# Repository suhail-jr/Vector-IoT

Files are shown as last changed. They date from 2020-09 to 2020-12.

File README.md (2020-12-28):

# Vector-IoT
Vector IoT : World’s smallest and powerful fully opensource  fully-featured ESP32 development board designed to unlock the power of the ESP32’s dual-core 240MHz and internet connectivity, in a package smaller than your thumb! Order your pcb from [jlcpcb.com](https://jlcpcb.com)

 ~ Current Status: Prototype boards sponsored by [jlcpcb.com](https://jlcpcb.com) ~
     
     Note: This design was performed in Eagle 9.2.0 , you will need a atleast eagle 9.2.0 or higher version to open and edit these source files. 
           # Chance for bugs : High

# Rendered Footage of the PCB

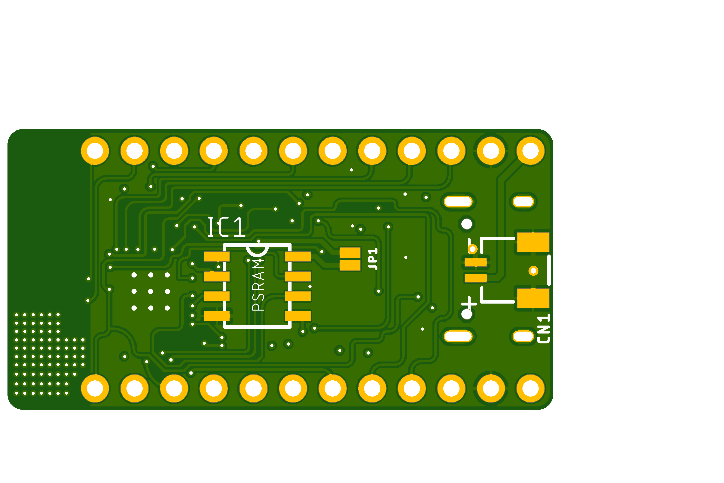
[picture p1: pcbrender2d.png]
Render

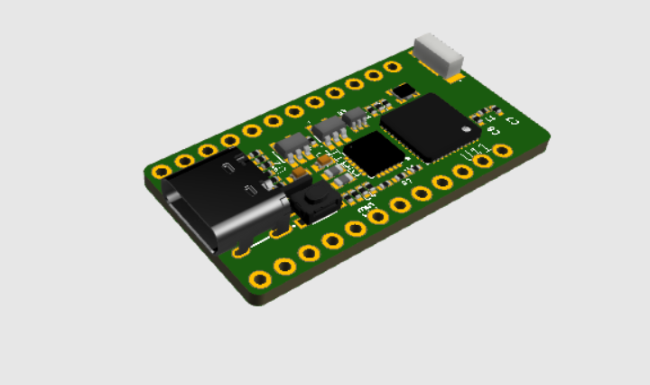
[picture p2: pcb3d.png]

## Licence
 * Hardware in this repository is licenced under Creative Commons BY-SA

 ## OSHW Certification
 TBD (Will apply when prototypes tested)

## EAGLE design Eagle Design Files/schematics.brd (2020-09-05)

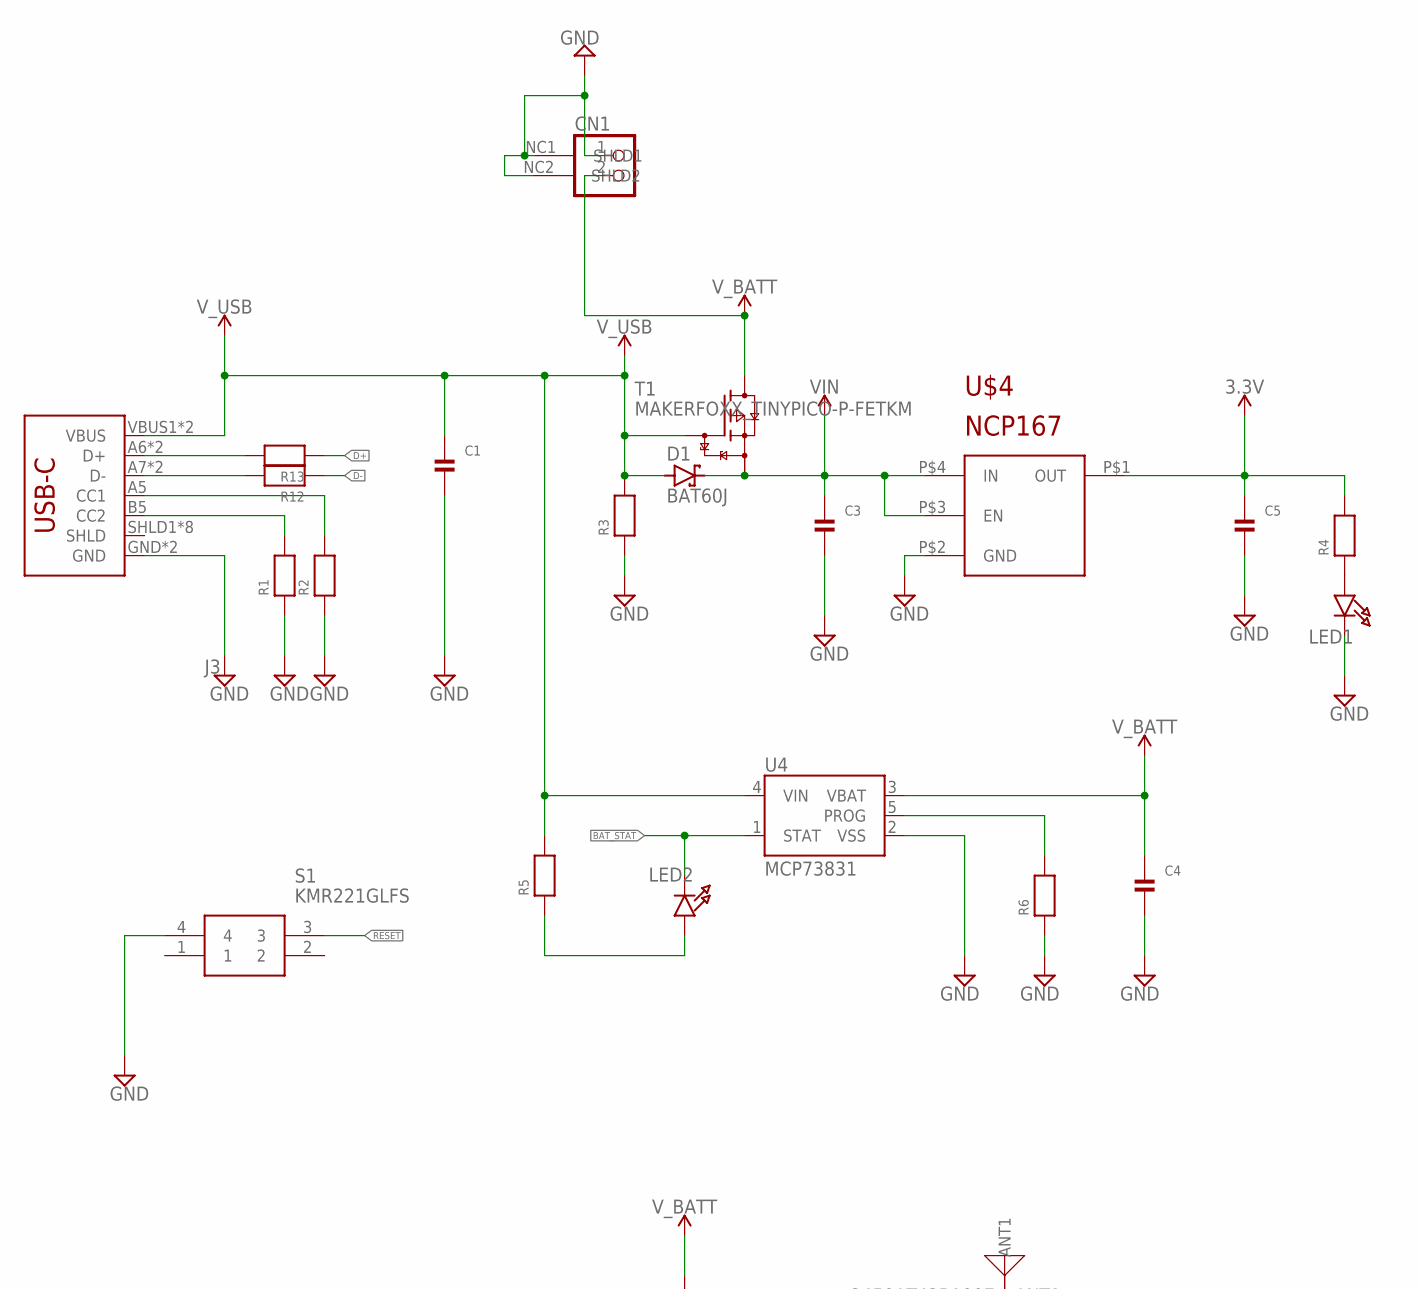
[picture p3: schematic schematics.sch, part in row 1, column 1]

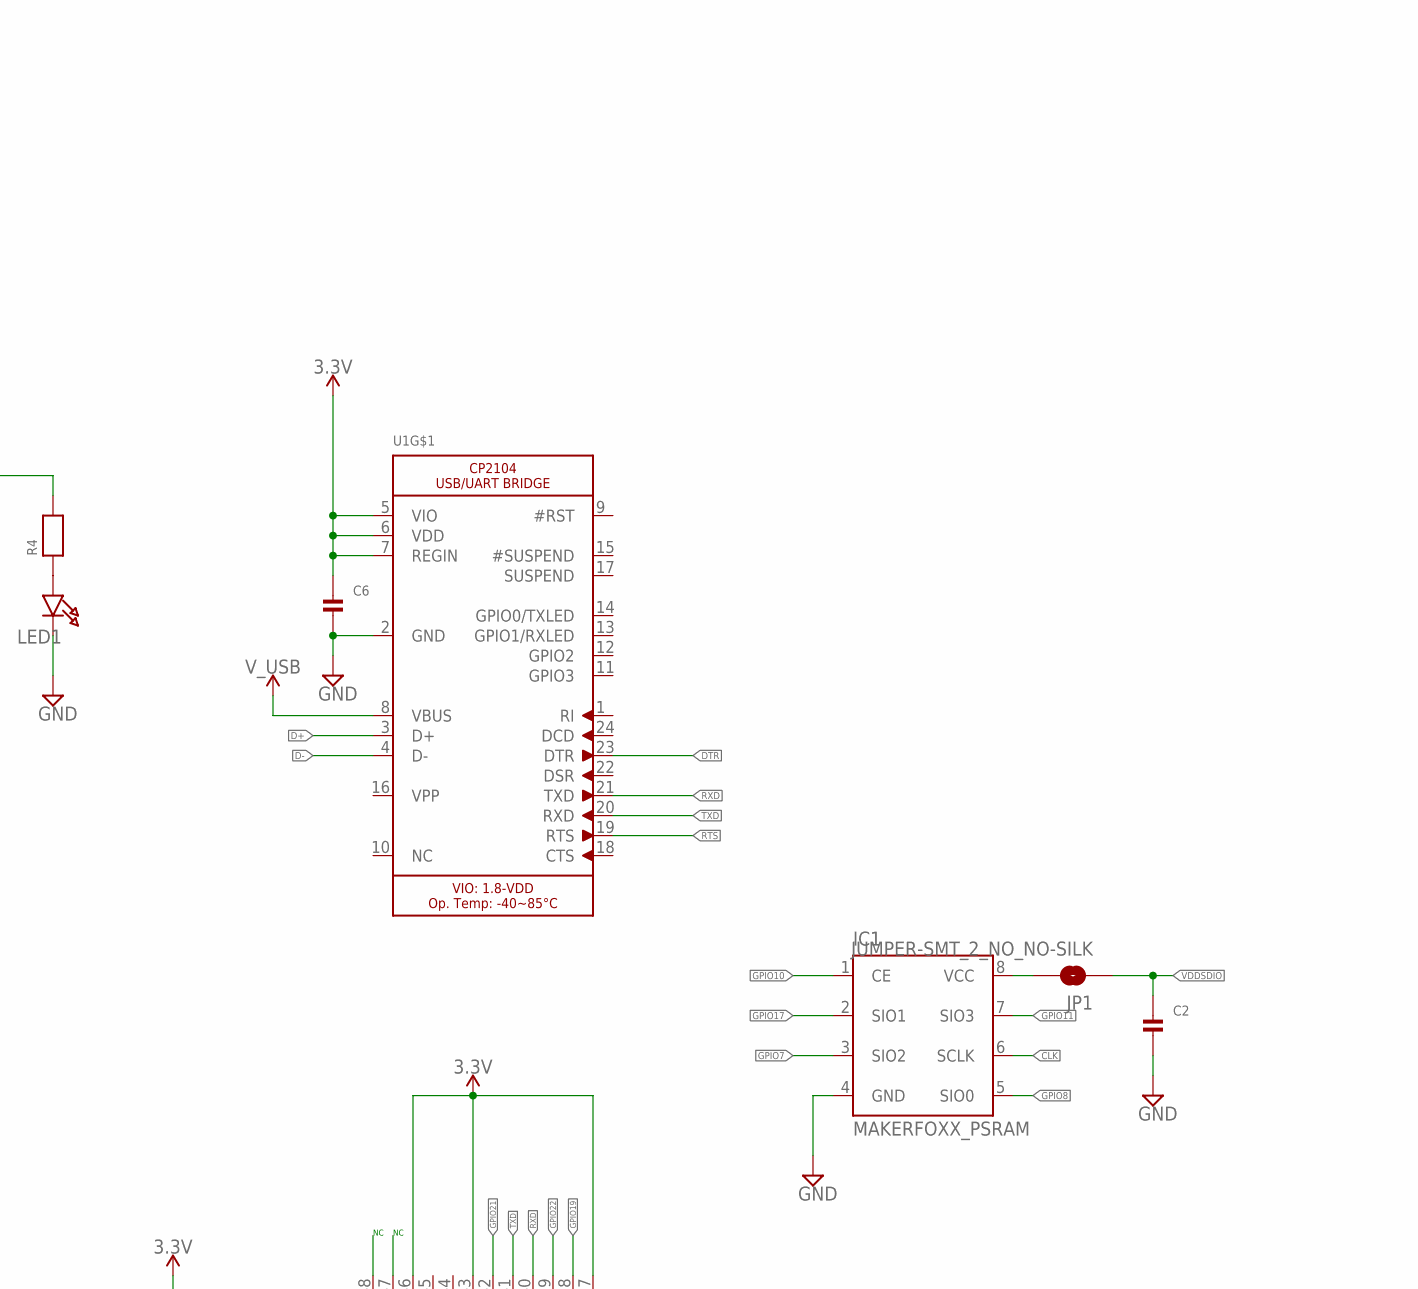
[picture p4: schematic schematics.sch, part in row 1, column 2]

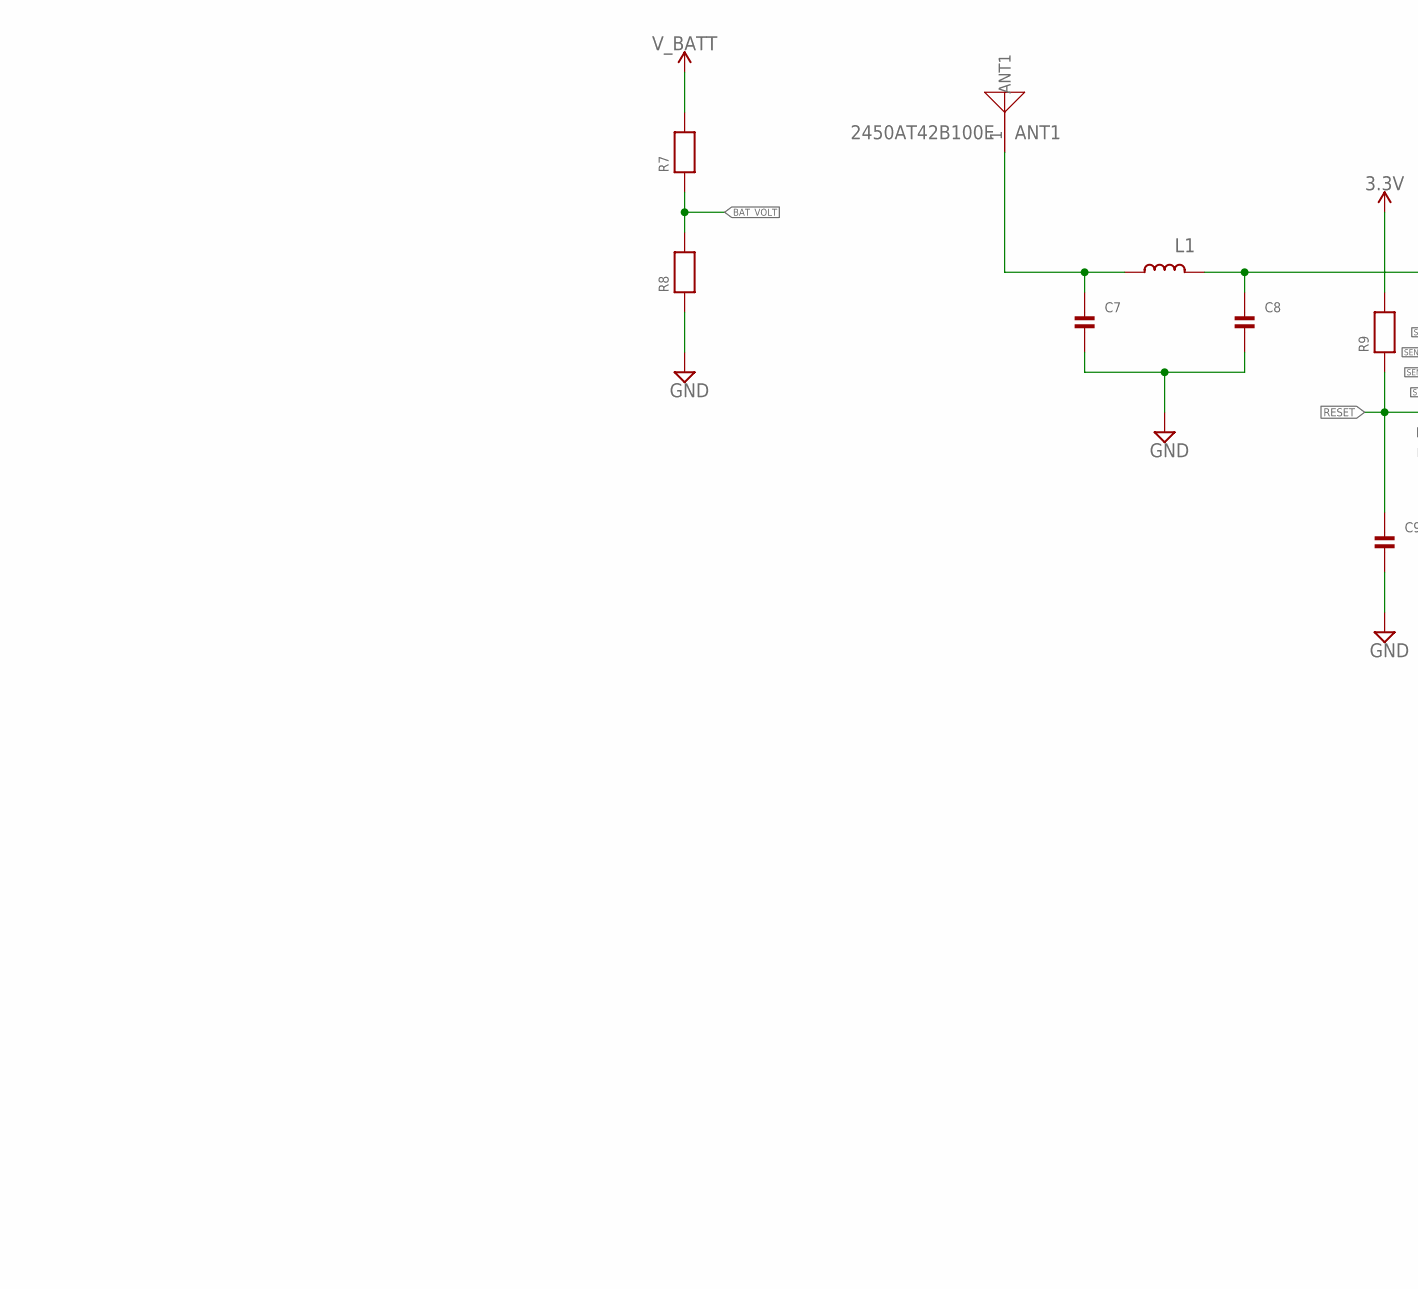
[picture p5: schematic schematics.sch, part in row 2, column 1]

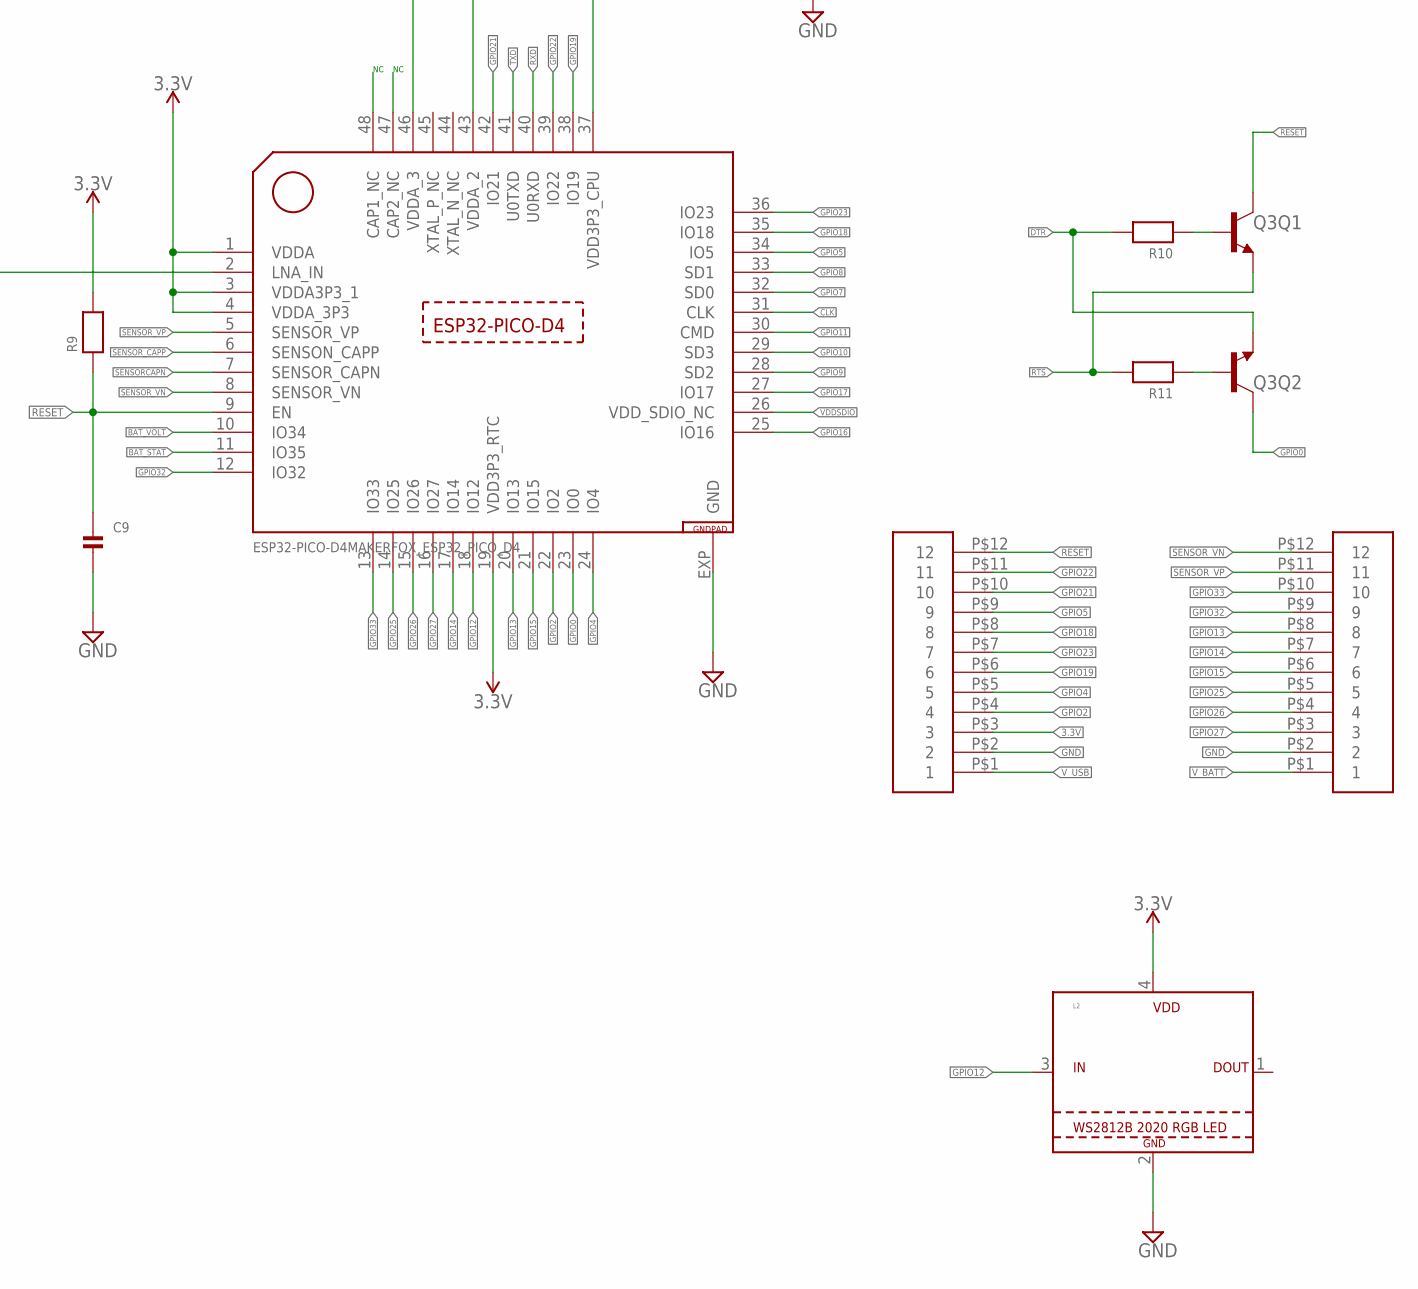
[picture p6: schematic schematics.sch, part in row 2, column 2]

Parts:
ANT1: 2450AT42B100E
C1, C6: CAP_CERAMIC_0603MP; _0603MP
C2, C3, C4, C5, C7, C8, C9: CAP_CERAMIC_0402MP; _0402MP
CN1: STANDARD_JST_2PINSH2; MAKERFOXX_JSTSH2
D1: BAT60J; SOD323_ST
IC1: MAKERFOXX_PSRAM; MAKERFOXX_SOP8
J3: USBC_USB_C5; USBC_USB-C-16P-5
JP1: JUMPER-SMT_2_NO_NO-SILK; SMT-JUMPER_2_NO_NO-SILK
L1: 3.9NH; _0402MP
L2: DISCRETE_NOA_WS2812B2020; DISCRETE_NOA_WS2812_2020
LED1, LED2: LED0603_NOOUTLINE; CHIPLED_0603_NOOUTLINE
Q3: MAKERFOXX_MBT3904DW1T1; MAKERFOXX_DUAL_NPN_SC70-6
R1, R2, R3, R4, R5, R6, R7, R8, R9, R10, R11, R12, R13: RESISTOR_0402MP; _0402MP
S1: KMR221GLFS; KMR2_1
T1: MAKERFOXX_TINYPICO-P-FETKM; MAKERFOXX_SOT883(B)
U1: CP2104_MICROBUILDER_CP2104; CP2104_MICROBUILDER_QFN24_4MM_SMSC
U4: MCP73831; SOT23-5
U$1: ESP32-PICO-D4MAKERFOX_ESP32_PICO_D4; MAKERFOXX_PICO-D4-QFN48
U$2, U$3: MAKEERFOXX_HEADER_12; HEADER_12_NO_SILK
U$4: NCP167; XDFN4

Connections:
3.3V: C5.1, C6.1, L2.4 (VDD), R4.2, R9.2, U1.5 (VIO), U1.6 (VDD), U1.7 (REGIN), U$1.1 (VDDA), U$1.3 (VDDA3P3_1), U$1.4 (VDDA_3P3), U$1.19 (VDD3P3_RTC), U$1.37 (VDD3P3_CPU), U$1.43 (VDDA_2), U$1.46 (VDDA_3), U$3.P$3 (3), U$4.P$1 (OUT)
BAT_STAT: LED2.C, U4.1 (STAT), U$1.11 (IO35)
BAT_VOLT: R7.1, R8.2, U$1.10 (IO34)
CLK: IC1.6 (SCLK), U$1.31 (CLK)
D+: R13.1, U1.3 (D+)
D-: R12.1, U1.4 (D-)
DTR: Q3.1 (E), R10.2, U1.23 (DTR)
GND: C1.2, C2.2, C3.2, C4.2, C5.2, C6.2, C7.2, C8.2, C9.2, CN1.1, CN1.NC1 (SHLD1), CN1.NC2 (SHLD2), IC1.4 (GND), J3.GND, J3.GND2 (GND), L2.2 (GND), LED1.C, R1.1, R2.1, R3.1, R6.1, R8.1, S1.4, U1.2 (GND), U4.2 (VSS), U$1.EXP (GND), U$2.P$2 (2), U$3.P$2 (2), U$4.P$2 (GND)
GPIO0: Q3.6 (C), U$1.23 (IO0)
GPIO2: U$1.22 (IO2), U$3.P$4 (4)
GPIO4: U$1.24 (IO4), U$3.P$5 (5)
GPIO5: U$1.34 (IO5), U$3.P$9 (9)
GPIO7: IC1.3 (SIO2), U$1.32 (SD0)
GPIO8: IC1.5 (SIO0), U$1.33 (SD1)
GPIO9: U$1.28 (SD2)
GPIO10: IC1.1 (CE), U$1.29 (SD3)
GPIO11: IC1.7 (SIO3), U$1.30 (CMD)
GPIO12: L2.3 (DIN), U$1.18 (IO12)
GPIO13: U$1.20 (IO13), U$2.P$8 (8)
GPIO14: U$1.17 (IO14), U$2.P$7 (7)
GPIO15: U$1.21 (IO15), U$2.P$6 (6)
GPIO16: U$1.25 (IO16)
GPIO17: IC1.2 (SIO1), U$1.27 (IO17)
GPIO18: U$1.35 (IO18), U$3.P$8 (8)
GPIO19: U$1.38 (IO19), U$3.P$6 (6)
GPIO21: U$1.42 (IO21), U$3.P$10 (10)
GPIO22: U$1.39 (IO22), U$3.P$11 (11)
GPIO23: U$1.36 (IO23), U$3.P$7 (7)
GPIO25: U$1.14 (IO25), U$2.P$5 (5)
GPIO26: U$1.15 (IO26), U$2.P$4 (4)
GPIO27: U$1.16 (IO27), U$2.P$3 (3)
GPIO32: U$1.12 (IO32), U$2.P$9 (9)
GPIO33: U$1.13 (IO33), U$2.P$10 (10)
IN: C3.1, D1.C, T1.2 (S), U$4.P$3 (EN), U$4.P$4 (IN)
unnamed: LED2.A, R5.1
unnamed: IC1.8 (VCC), JP1.2
unnamed: Q3.5 (B), R10.1
unnamed: R6.2, U4.5 (PROG)
unnamed: LED1.A, R4.1
unnamed: Q3.2 (B), R11.1
unnamed: C8.1, L1.2, U$1.2 (LNA_IN)
unnamed: ANT1.1, C7.1, L1.1
unnamed: J3.A7 (D-), J3.B7 (D-), R12.2
unnamed: J3.A6 (D+), J3.B6 (D+), R13.2
unnamed: J3.A5 (CC1), R2.2
unnamed: J3.B5 (CC2), R1.2
RESET: C9.1, Q3.3 (C), R9.1, S1.3, U$1.9 (EN), U$3.P$12 (12)
RTS: Q3.4 (E), R11.2, U1.19 (RTS)
RXD: U1.21 (TXD), U$1.40 (U0RXD)
SENSORCAPN: U$1.7 (SENSOR_CAPN)
SENSOR_CAPP: U$1.6 (SENSON_CAPP)
SENSOR_VN: U$1.8 (SENSOR_VN), U$2.P$12 (12)
SENSOR_VP: U$1.5 (SENSOR_VP), U$2.P$11 (11)
TP: U1.THERM (TP)
TXD: U1.20 (RXD), U$1.41 (U0TXD)
VDDSDIO: C2.1, JP1.1, U$1.26 (VDD_SDIO_NC)
V_BATT: C4.1, CN1.2, R7.2, T1.3 (D), U4.3 (VBAT), U$2.P$1 (1)
V_USB: C1.1, D1.A, J3.VBUS1 (VBUS), J3.VBUS2 (VBUS), R3.2, R5.2, T1.1 (G), U1.8 (VBUS), U4.4 (VIN), U$3.P$1 (1)

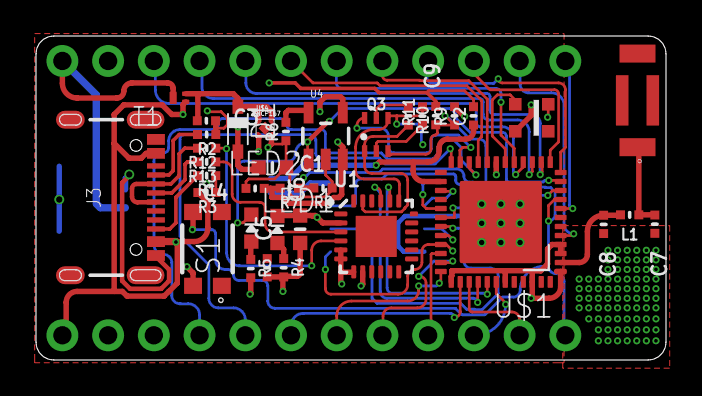
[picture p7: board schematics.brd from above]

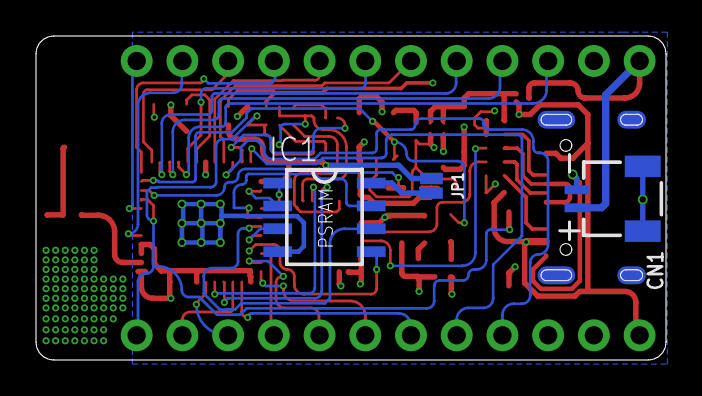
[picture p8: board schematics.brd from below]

Board: 4 copper layers, 35.0 x 18.0 mm, 41 parts (3 on the bottom side), 53 nets.

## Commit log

2020-09-05 Added Initial Files
    [schematics.brd, schematics.sch]
2020-12-29 Changed Directory
    [schematics.brd, schematics.sch]

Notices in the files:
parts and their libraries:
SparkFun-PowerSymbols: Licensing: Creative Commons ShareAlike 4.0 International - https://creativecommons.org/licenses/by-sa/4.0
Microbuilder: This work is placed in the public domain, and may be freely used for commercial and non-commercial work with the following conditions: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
